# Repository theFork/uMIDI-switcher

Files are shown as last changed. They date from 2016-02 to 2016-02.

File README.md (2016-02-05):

# uMIDI switcher
Effect switching module based on uMIDI.

* 5 true-bypass loopers
* 2 general purpose switches
* Tuner output
* 3 9V outputs connected to 6 barrel jacks
* 12V input via barrel jack

## Control panel
There are nine illuminated momentary switches on the control panel:

* 1x Mute/Tune (red)
* 5x Looper (green)
* 2x Switch (blue, small)
* 1x Save (red, small)

Except for the "Save" button, the switch LED is synchronously switched with the corresponding relais. It is possible to hard-wire these LEDs to the switch PCB's inputs. The "Save" button should blink to indicate unsaved changes.

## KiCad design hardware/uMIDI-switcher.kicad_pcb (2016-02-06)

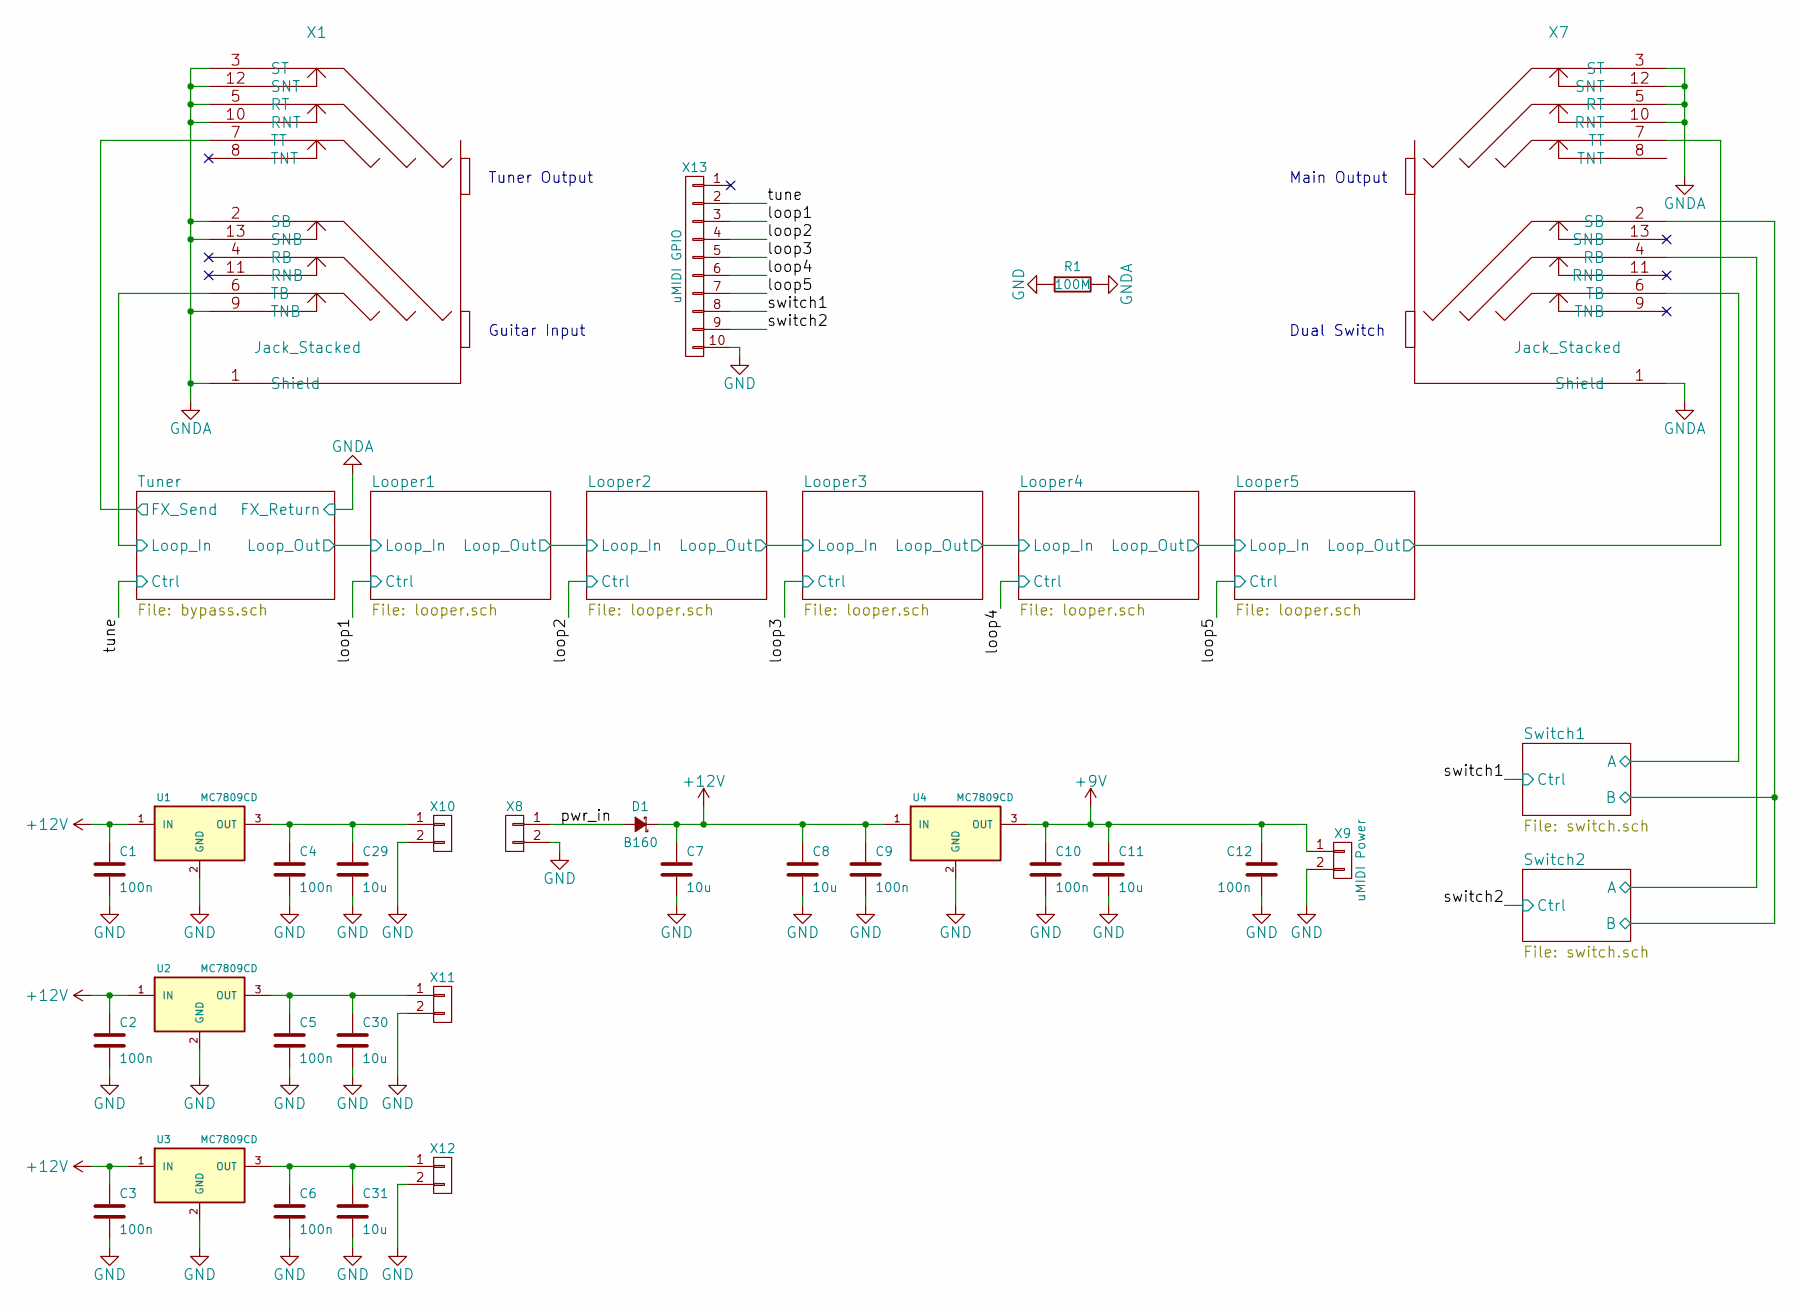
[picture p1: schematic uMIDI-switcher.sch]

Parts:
C1, C2, C3, C4, C5, C6, C9, C10, C12: 100n; C_0603; Manufacturer Part Number GRM188R71E104KA01D
C7, C8, C11, C29, C30, C31: 10u; C_0805; Manufacturer Part Number GRM21BR61E106KA73L
D1: B160; SMA_Standard; Manufacturer Part Number B160-13-F
R1: 100M; R_0603; Manufacturer Part Number CRCW0603100MJPEAHR
U1, U2, U3, U4: MC7809CD; D2PAK-3; Manufacturer Part Number MC7809CD2TG
X1, X7: Jack_Stacked; NSJ12HF-1; Manufacturer Part Number NSJ12HF-1
X8: 12V in; PINHEAD-Supply
X9: uMIDI Power; PINHEAD-Supply
X10, X11, X12: CONN_01X02; PINHEAD-Supply
X13: uMIDI GPIO; VASCH5x2; Manufacturer Part Number 30310-6002HB

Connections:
+9V: C10.1, C11.1, C12.1, U4.3 (OUT), X9.1; also elsewhere on the board
+12V: C1.1, C2.1, C3.1, C7.1, C8.1, C9.1, D1.1 (K), U1.1 (IN), U2.1 (IN), U3.1 (IN), U4.1 (IN)
/Looper1/Ctrl: X13.3; also elsewhere on the board
/Looper2/Ctrl: X13.4; also elsewhere on the board
/Looper3/Ctrl: X13.5; also elsewhere on the board
/Looper4/Ctrl: X13.6; also elsewhere on the board
/Looper5/Ctrl: X13.7; also elsewhere on the board
/Looper5/Loop_Out: X7.7 (TT); also elsewhere on the board
/Switch1/A: X7.6 (TB); also elsewhere on the board
/Switch1/B: X7.2 (SB); also elsewhere on the board
/Switch1/Ctrl: X13.8; also elsewhere on the board
/Switch2/A: X7.4 (RB); also elsewhere on the board
/Switch2/Ctrl: X13.9; also elsewhere on the board
/Tuner/Ctrl: X13.2; also elsewhere on the board
/Tuner/FX_Send: X1.7 (TT); also elsewhere on the board
/Tuner/Loop_In: X1.6 (TB); also elsewhere on the board
/pwr_in: D1.2 (A), X8.1
GND: C1.2, C2.2, C3.2, C4.2, C5.2, C6.2, C7.2, C8.2, C9.2, C10.2, C11.2, C12.2, C29.2, C30.2, C31.2, R1.2, U1.2 (GND), U2.2 (GND), U3.2 (GND), U4.2 (GND), X8.2, X9.2, X10.2, X11.2, X12.2, X13.10; also elsewhere on the board
unnamed: C4.1, C29.1, U1.3 (OUT), X10.1
unnamed: C5.1, C30.1, U2.3 (OUT), X11.1
unnamed: C6.1, C31.1, U3.3 (OUT), X12.1

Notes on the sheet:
Guitar Input
Tuner Output
Main Output
Dual Switch

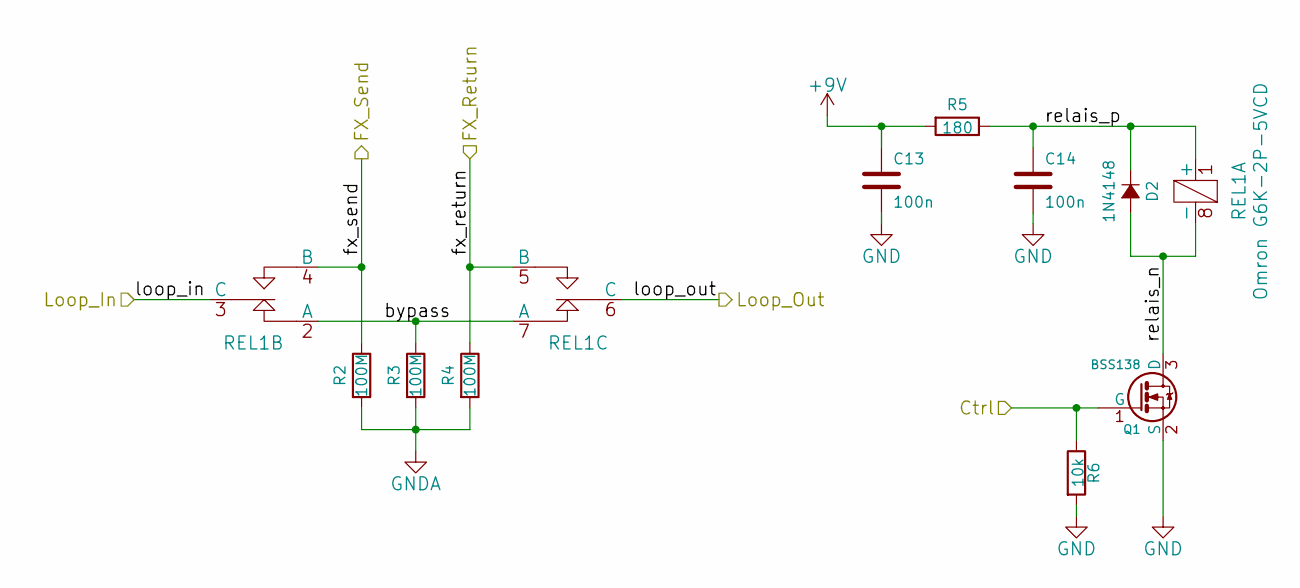
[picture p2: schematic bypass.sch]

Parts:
C13, C14: 100n; C_0603; Manufacturer Part Number GRM188R71E104KA01D
D2: 1N4148; SOD-123; Manufacturer Part Number 1N4148W-7-F
Q1: BSS138; SOT-23; Manufacturer Part Number BSS138
R2, R3, R4: 100M; R_0603; Manufacturer Part Number CRCW0603100MJPEAHR
R5: 180; R_0603; Manufacturer Part Number CRCW0603180RJNEA
R6: 10k; R_0603; Manufacturer Part Number CRCW060310K0JNEA
REL1: Omron G6K-2P-5VCD; Omron_G6K-2P; Manufacturer Part Number G6K-2P-Y-DC5

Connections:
+9V: C13.1, R5.2; also elsewhere on the board
/Looper1/Loop_In: REL1.6 (C); also elsewhere on the board
/Tuner/Ctrl: Q1.1 (G), R6.1; also elsewhere on the board
/Tuner/FX_Send: R2.1, REL1.4 (B); also elsewhere on the board
/Tuner/Loop_In: REL1.3 (C); also elsewhere on the board
/Tuner/bypass: R3.1, REL1.2 (A), REL1.7 (A)
/Tuner/relais_n: D2.2 (A), Q1.3 (D), REL1.8 (-)
/Tuner/relais_p: C14.1, D2.1 (K), R5.1, REL1.1 (+)
GND: C13.2, C14.2, Q1.2 (S), R6.2; also elsewhere on the board

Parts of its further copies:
C15, C16, C17, C18, C19, C20, C21, C22, C23, C24: 100n; C_0603; Manufacturer Part Number GRM188R71E104KA01D
D3, D4, D5, D6, D7: 1N4148; SOD-123; Manufacturer Part Number 1N4148W-7-F
Q2, Q3, Q4, Q5, Q6: BSS138; SOT-23; Manufacturer Part Number BSS138
R7, R8, R9, R12, R13, R14, R17, R18, R19, R22, R23, R24, R27, R28, R29: 100M; R_0603; Manufacturer Part Number CRCW0603100MJPEAHR
R10, R15, R20, R25, R30: 180; R_0603; Manufacturer Part Number CRCW0603180RJNEA
R11, R16, R21, R26, R31: 10k; R_0603; Manufacturer Part Number CRCW060310K0JNEA
REL2, REL3, REL4, REL5, REL6: Omron G6K-2P-5VCD; Omron_G6K-2P; Manufacturer Part Number G6K-2P-Y-DC5

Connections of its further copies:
+9V: C15.1, C17.1, C19.1, C21.1, C23.1, R10.2, R15.2, R20.2, R25.2, R30.2; also elsewhere on the board
/Looper1/Ctrl: Q6.1 (G), R31.1; also elsewhere on the board
/Looper1/Loop_In: REL2.3 (C); also elsewhere on the board
/Looper1/Single True Bypass/FX_Return: R29.1, REL2.5 (B); also elsewhere on the board
/Looper1/Single True Bypass/FX_Send: R27.1, REL2.4 (B); also elsewhere on the board
/Looper1/Single True Bypass/bypass: R28.1, REL2.2 (A), REL2.7 (A)
/Looper1/Single True Bypass/relais_n: D7.2 (A), Q6.3 (D), REL2.8 (-)
/Looper1/Single True Bypass/relais_p: C24.1, D7.1 (K), R30.1, REL2.1 (+)
/Looper2/Ctrl: Q2.1 (G), R11.1; also elsewhere on the board
/Looper2/Loop_In: REL2.6 (C), REL3.3 (C)
/Looper2/Single True Bypass/FX_Send: R7.1, REL3.4 (B); also elsewhere on the board
/Looper2/Single True Bypass/bypass: R8.1, REL3.2 (A), REL3.7 (A)
/Looper2/Single True Bypass/relais_n: D3.2 (A), Q2.3 (D), REL3.8 (-)
/Looper2/Single True Bypass/relais_p: C16.1, D3.1 (K), R10.1, REL3.1 (+)
/Looper3/Ctrl: Q3.1 (G), R16.1; also elsewhere on the board
/Looper3/Loop_In: REL3.6 (C), REL4.3 (C)
/Looper3/Single True Bypass/FX_Return: R14.1, REL4.5 (B); also elsewhere on the board
/Looper3/Single True Bypass/FX_Send: R12.1, REL4.4 (B); also elsewhere on the board
/Looper3/Single True Bypass/bypass: R13.1, REL4.2 (A), REL4.7 (A)
/Looper3/Single True Bypass/relais_n: D4.2 (A), Q3.3 (D), REL4.8 (-)
/Looper3/Single True Bypass/relais_p: C18.1, D4.1 (K), R15.1, REL4.1 (+)
/Looper4/Ctrl: Q4.1 (G), R21.1; also elsewhere on the board
/Looper4/Loop_In: REL4.6 (C), REL5.3 (C)
/Looper4/Single True Bypass/FX_Return: R19.1, REL5.5 (B); also elsewhere on the board
/Looper4/Single True Bypass/FX_Send: R17.1, REL5.4 (B); also elsewhere on the board
/Looper4/Single True Bypass/bypass: R18.1, REL5.2 (A), REL5.7 (A)
/Looper4/Single True Bypass/relais_n: D5.2 (A), Q4.3 (D), REL5.8 (-)
/Looper4/Single True Bypass/relais_p: C20.1, D5.1 (K), R20.1, REL5.1 (+)
/Looper5/Ctrl: Q5.1 (G), R26.1; also elsewhere on the board
/Looper5/Loop_In: REL5.6 (C), REL6.3 (C)
/Looper5/Loop_Out: REL6.6 (C); also elsewhere on the board
/Looper5/Single True Bypass/FX_Return: R24.1, REL6.5 (B); also elsewhere on the board
/Looper5/Single True Bypass/FX_Send: R22.1, REL6.4 (B); also elsewhere on the board
/Looper5/Single True Bypass/bypass: R23.1, REL6.2 (A), REL6.7 (A)
/Looper5/Single True Bypass/relais_n: D6.2 (A), Q5.3 (D), REL6.8 (-)
/Looper5/Single True Bypass/relais_p: C22.1, D6.1 (K), R25.1, REL6.1 (+)
GND: C15.2, C16.2, C17.2, C18.2, C19.2, C20.2, C21.2, C22.2, C23.2, C24.2, Q2.2 (S), Q3.2 (S), Q4.2 (S), Q5.2 (S), Q6.2 (S), R11.2, R16.2, R21.2, R26.2, R31.2; also elsewhere on the board

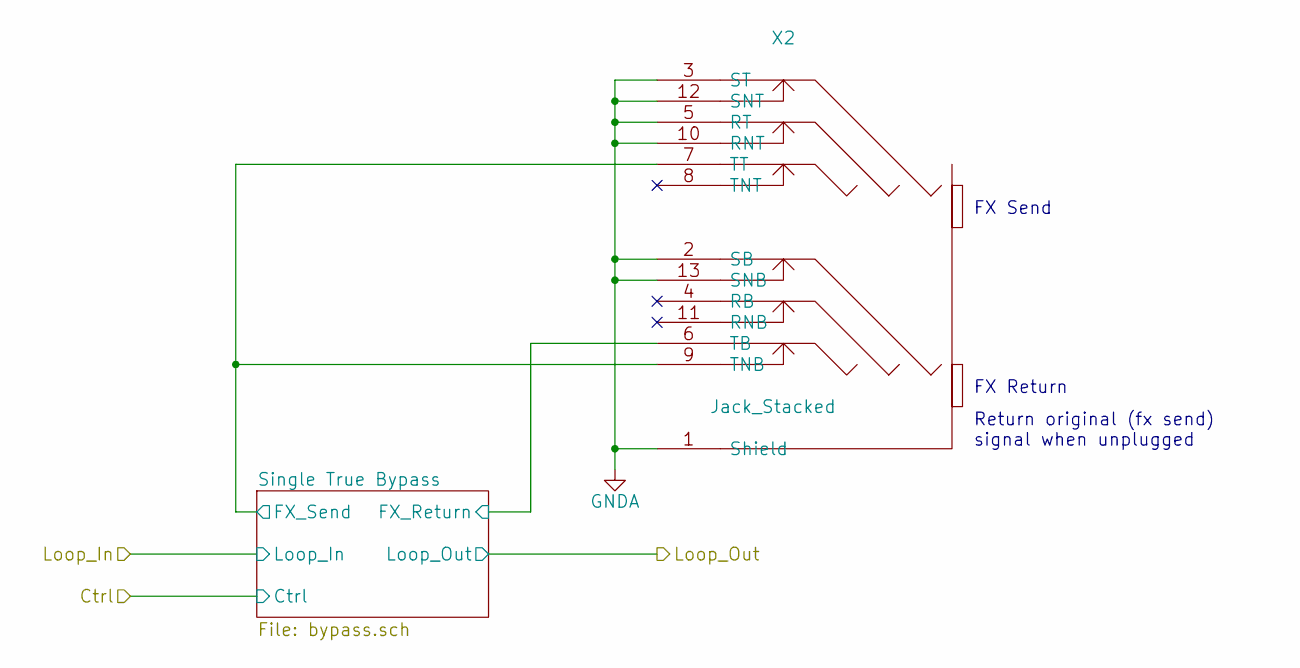
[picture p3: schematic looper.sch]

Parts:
X3: Jack_Stacked; NSJ12HF-1; Manufacturer Part Number NSJ12HF-1

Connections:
/Looper2/Single True Bypass/FX_Send: X3.7 (TT), X3.9 (TNB); also elsewhere on the board

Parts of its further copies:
X2, X4, X5, X6: Jack_Stacked; NSJ12HF-1; Manufacturer Part Number NSJ12HF-1

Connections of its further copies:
/Looper1/Single True Bypass/FX_Return: X2.6 (TB); also elsewhere on the board
/Looper1/Single True Bypass/FX_Send: X2.7 (TT), X2.9 (TNB); also elsewhere on the board
/Looper3/Single True Bypass/FX_Return: X4.6 (TB); also elsewhere on the board
/Looper3/Single True Bypass/FX_Send: X4.7 (TT), X4.9 (TNB); also elsewhere on the board
/Looper4/Single True Bypass/FX_Return: X5.6 (TB); also elsewhere on the board
/Looper4/Single True Bypass/FX_Send: X5.7 (TT), X5.9 (TNB); also elsewhere on the board
/Looper5/Single True Bypass/FX_Return: X6.6 (TB); also elsewhere on the board
/Looper5/Single True Bypass/FX_Send: X6.7 (TT), X6.9 (TNB); also elsewhere on the board

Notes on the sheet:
FX Send
FX Return
Return original (fx send) signal when unplugged

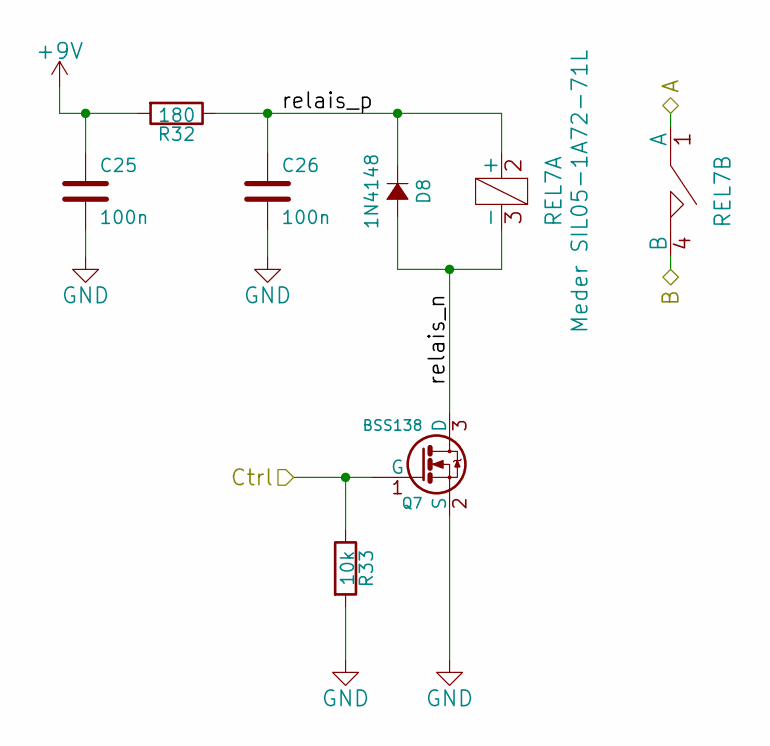
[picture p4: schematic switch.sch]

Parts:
C25, C26: 100n; C_0603; Manufacturer Part Number GRM188R71E104KA01D
D8: 1N4148; SOD-123; Manufacturer Part Number 1N4148W-7-F
Q7: BSS138; SOT-23; Manufacturer Part Number BSS138
R32: 180; R_0603; Manufacturer Part Number CRCW0603180RJNEA
R33: 10k; R_0603; Manufacturer Part Number CRCW060310K0JNEA
REL7: Meder SIL05-1A72-71L; Meder_SIL; Part Number SIL 7271-L 5V

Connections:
+9V: C25.1, R32.2; also elsewhere on the board
/Switch1/A: REL7.1 (A); also elsewhere on the board
/Switch1/B: REL7.4 (B); also elsewhere on the board
/Switch1/Ctrl: Q7.1 (G), R33.1; also elsewhere on the board
/Switch1/relais_n: D8.2 (A), Q7.3 (D), REL7.3 (-)
/Switch1/relais_p: C26.1, D8.1 (K), R32.1, REL7.2 (+)
GND: C25.2, C26.2, Q7.2 (S), R33.2; also elsewhere on the board

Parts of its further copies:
C27, C28: 100n; C_0603; Manufacturer Part Number GRM188R71E104KA01D
D9: 1N4148; SOD-123; Manufacturer Part Number 1N4148W-7-F
Q8: BSS138; SOT-23; Manufacturer Part Number BSS138
R34: 180; R_0603; Manufacturer Part Number CRCW0603180RJNEA
R35: 10k; R_0603; Manufacturer Part Number CRCW060310K0JNEA
REL8: Meder SIL05-1A72-71L; Meder_SIL; Part Number SIL 7271-L 5V

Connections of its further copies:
+9V: C27.1, R34.2; also elsewhere on the board
/Switch1/B: REL8.4 (B); also elsewhere on the board
/Switch2/A: REL8.1 (A); also elsewhere on the board
/Switch2/Ctrl: Q8.1 (G), R35.1; also elsewhere on the board
/Switch2/relais_n: D9.2 (A), Q8.3 (D), REL8.3 (-)
/Switch2/relais_p: C28.1, D9.1 (K), R34.1, REL8.2 (+)
GND: C27.2, C28.2, Q8.2 (S), R35.2; also elsewhere on the board

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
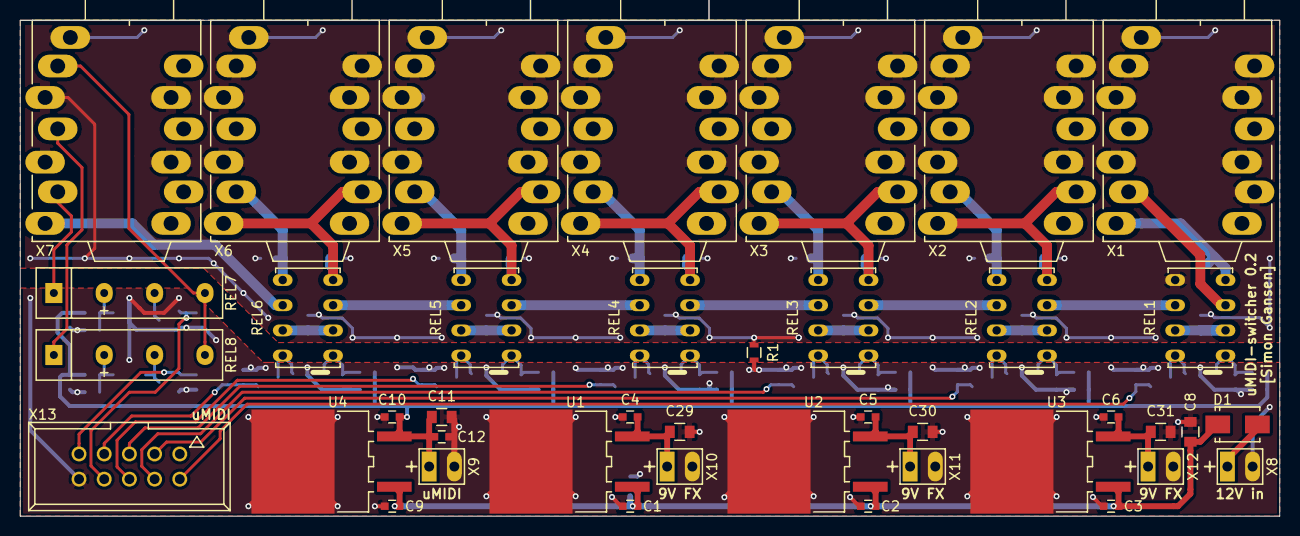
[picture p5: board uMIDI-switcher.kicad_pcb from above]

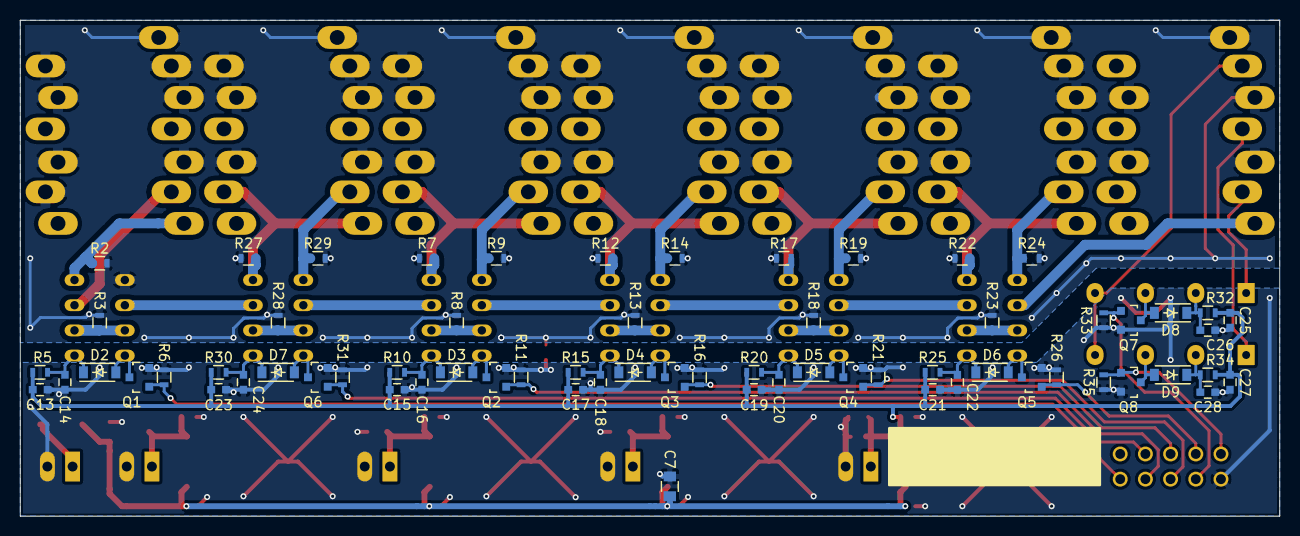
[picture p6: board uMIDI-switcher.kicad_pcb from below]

Board: 2 copper layers, 127.0 x 50.0 mm, 107 parts (66 on the bottom side), 59 nets.

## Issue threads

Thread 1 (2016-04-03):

uMIDI

theFork, 2016-04-03:
uMIDI boards connected to the 9V power output of the switchers get destroyed somehow. Apparently this happens when an effect is connected to an external 9V output in reverse polarity.

- [x] Do the defective boards still respond to the PDI programmer?
- [ ] Construct a test circuit (without uMIDI board) and measure peak voltages when connecting a diode in forward direction to a 9V output
- [ ] Add a (defective) uMIDI board and observe the peaks at the in- and output of the 3.3V LDO. Do we exceed the MCUs maximum voltage ratings?
- [ ] Develop protection circuit, modify existing boards, test and update current design files.

haggl, 2016-04-03:
Apparently, this can be fixed by re-installing the software. It looks like a block of data was somehow erased from FLASH memory. Here are two images - the first one was read out from the chip after the incident occured and the second one was is the same commit, rebuilt from scratch with make clean compile, flashed to the device and read back:
[flash-d5686b7-broken.hex.txt](https://github.com/theFork/uMIDI-switcher/files/201403/flash-d5686b7-broken.hex.txt)
[flash-d5686b7-ok.hex.txt](https://github.com/theFork/uMIDI-switcher/files/201402/flash-d5686b7-ok.hex.txt)

Creepy. oO

theFork, 2016-04-09:
Reproduced with the following setup (I only wanted to update the firmware):
- Guitar Effects connected to the 9V outputs, floorboard (consuming from 12V) connected
- 12V wall adapter not connected (thus the floorboard should not matter)
- Used a long USB cable to connect a host via a USB hub
  - Hub support USB 3.x
  - Is externally powered from the far end of the room
  - Different grounds due to SMPS?

theFork, 2016-04-21:
It happened again, this time without the USB hub.

* No USB devices is detected when connecting the board
* The red onboard LED flashes during startup, but the Tune/Mute LED does not turn on

avrdude -c atmelice_pdi -p x128a4u -U flash:r:flash.bin:b && hexdump flash.bin > [flash.hex.txt](https://github.com/theFork/uMIDI-switcher/files/230243/flash.hex.txt)

Reading out the fuses....
```
avrdude -c atmelice_pdi -p x128a4u -U fuse1:r:-:h
0x0

avrdude -c atmelice_pdi -p x128a4u -U fuse2:r:-:h
0xbf

avrdude -c atmelice_pdi -p x128a4u -U fuse4:r:-:h
0xfe

avrdude -c atmelice_pdi -p x128a4u -U fuse5:r:-:h
0xff
```
These values should be checked for sanity. Maybe this will give us a hint (?)

haggl, 2016-05-20:
This issue can be closed, right?

theFork, 2016-05-23:
Jepp.

Closed 2016-05-23.

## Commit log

2015-10-16 Remove led distribution
    [bypass.sch, looper.sch, loopers.sch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]
2015-10-16 Use smd regulators
    [uMIDI-switcher.kicad_pcb, uMIDI-switcher.sch]
2015-10-16 Use schottky diode for input protection
    [uMIDI-switcher.kicad_pcb, uMIDI-switcher.sch]
2015-10-16 Integrate sheet looper.sch into top level sheet
    [bypass.sch, looper.sch, loopers.sch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]
2015-10-16 Add optional gnd-gnda resistor
    [bypass.sch, looper.sch, uMIDI-switcher.sch]
2015-10-19 Change D1 supplier
    [bypass.sch, uMIDI-switcher.sch]
2015-10-19 Unify part fields
    [uMIDI-switcher.sch]
2015-10-19 Change LDO supplier
    [bypass.sch, looper.sch, switch.sch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]
2015-10-23 Add some component fields; Change 10uF footprint
    [bypass.sch, looper.sch, switch.sch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]
2015-10-24 Determine relay resistor
    [bypass.sch, switch.sch]
2015-11-19 Fix ribbon connector supplier fields
    [uMIDI-switcher.sch]
2015-11-20 Straighten annotation and placement
    [bypass.sch, looper.sch, uMIDI-switcher.kicad_pcb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]
2015-11-20 Remove tuner signal to GNDA resistor (only on board)
    [uMIDI-switcher.kicad_pcb]
2015-11-20 Assign net classes
    [uMIDI-switcher.kicad_pcb]
2015-11-20 Use two layers; Shrink placement
    [uMIDI-switcher.kicad_pcb]
2015-11-20 Route everything except GND(A)
    [uMIDI-switcher.kicad_pcb]
2015-11-20 Add GND and GNDA planes
    [uMIDI-switcher.kicad_pcb]
2015-11-26 Revise omron relais footprint (silk only)
    [uMIDI-switcher.kicad_pcb]
2015-11-26 Add fitting footprint for voltage regulators
2015-11-26 Use new ldo footprint; Adapt placement
    [bypass.sch, looper.sch, uMIDI-switcher.kicad_pcb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]
2015-11-26 Place and route
    [uMIDI-switcher.kicad_pcb]
2015-11-26 Add 10uF caps to 9V outputs; Place and route
    [bypass.sch, looper.sch, switch.sch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]
2015-11-27 Finish routing
    [uMIDI-switcher.kicad_pcb]
2015-11-27 Revise pcb (and some footprints) silk screen
    [uMIDI-switcher.kicad_pcb]
2015-11-29 Revise bottom silk screen; DRC clean
    [uMIDI-switcher.kicad_pcb]
2015-11-30 Fix major footprint fuckups...
    [bypass.sch, looper.sch, switch.sch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]
2015-11-30 Revise silkscreen
    [uMIDI-switcher.kicad_pcb]
2015-11-30 Add gerber archive
2015-12-18 Fix faulty jack connections
    [bypass.sch, looper.sch, uMIDI-switcher.kicad_pcb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]
2015-12-18 Fix some silkscreen designators
    [uMIDI-switcher.kicad_pcb]
2015-12-18 Increase size of polarity markers
    [uMIDI-switcher.kicad_pcb]
2015-12-18 Add comment area to bottom silk
    [uMIDI-switcher.kicad_pcb]
2015-12-18 Update gerber files
2016-01-05 Add backside drill plan
    [uMIDI-switcher.kicad_pcb]
2016-02-05 Add control panel concept and drawing
    [uMIDI-switcher.kicad_pcb]
2016-02-06 Revise control panel drawing
    [uMIDI-switcher.kicad_pcb]
